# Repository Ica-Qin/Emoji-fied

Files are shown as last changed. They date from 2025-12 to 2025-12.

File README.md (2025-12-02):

# Emoji-fied: Tangible Emotion-to-Bitmap Machine System
## Advanced-Final-Project-Peiyang-Qin

*A physical installation visualising how machines simplify and categorise human emotions.*

[Thesis](PeiyangQin_Emoji-fied.pdf)

---

## ⭐ Overview

This project builds a complete real-time pipeline that transforms **facial expression → emotion label → bitmap → printed material output**.  
Using an OpenMV CAM 7 Plus, Arduino Mega 2560 Pro, three thermal printers and 4 fans, the system materialises the computational reduction of human emotion into discrete, machine-readable “signals”.

The installation visualises the hidden process of emoji-fication described in the thesis.

---

## 🎬 Demo Video

https://github.com/user-attachments/assets/3ee92d83-e0cc-42b4-839e-c0125d08e00f

---

## 🖼 Showcase Photo

showcase03

showcase01

test2
test3


---

## 🧩 System Overview

### 1. Facial Input (OpenMV CAM 7 Plus)
- Real-time face detection  
- Lightweight expression classifier trained with FER2013 + custom photos  
- Bitmap conversion and serial transmission  
- Outputs: **emotion label + confidence score + 1-bit bitmap**  

### 2. Arduino Mega 2560 Pro (Central Controller)
- Receives serial data from OpenMV  
- Routes print jobs using **three hardware serial ports**  
- Manages thermal printers and fan activation  
- Operates printers at **9600 baud** (115200 produced garbled output)  

### 3. Thermal Printers (3-way categorical output)
| Printer | Paper Colour | Emotion Categories |
|---|---|---|
| Printer 1 | Yellow | Happy, Surprise |
| Printer 2 | Blue | Sad |
| Printer 3 | Green | Fear, Angry |

### 4. Mechanical Output (Fan)
- Fan activates for **30 seconds** after each print  
- Creates drifting movement to emphasise emotion, “signals” becoming simplified or lost  

---

## 🔧 Hardware

- OpenMV CAM 7 Plus  
- Arduino Mega 2560 Pro  
- 58mm thermal printers × 3  
- LM2596 buck converter (9V → 5V)  
- Relay module (fan control)  
- 9V power supply  
- Aluminium linear shafts + 3D printed brackets  
- PVC plates + iron net for airflow shaping  

---

## 💻 Code

### 📁 [OpenMV Code](Codes/OpenMV.py)
- Face detection  
- Emotion classification  
- Bitmap generation  
- Serial output  

### 📁 [Arduino Code](Codes/Arduino)
- Receives bitmap + emotion score  
- Chooses printer port  
- Sends bitmap to printer  
- Activates fan

### Logs
[Development Logs](Development_Log.md)

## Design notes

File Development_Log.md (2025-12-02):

# Development & Iteration Log  
*Process documentation for OpenMV + Arduino system*

This document records the major iterations, problems and decisions made during the development of the installation.  
It is divided into two parts: **OpenMV iterations** and **Arduino iterations**.

---

# 1. OpenMV Iterations

## 1.1 Initial Attempt: Custom CNN Model (Failed)
- Trained a CNN using **Keras + FER2013** on PC.
- Converted the model into **TensorFlow Lite**.
- Attempted to load on OpenMV CAM 7 Plus.
- **Issues encountered:**
  - OpenMV did not have enough RAM → *MemoryError*
  - Unsupported TFLite operators → *conversion failure*
  - Inference speed too slow → *not real-time*
 
屏幕截图 2025-11-25 004311

- **Decision:** Abandon custom model and switch to OpenMV’s built-in lightweight classifier.

---

## 1.2 Switching to Built-in Expression Classifier
- Adopted OpenMV’s example model for **emotion classification**.
- Advantages:
  - Real-time inference
  - Fully compatible with OpenMV hardware
  - Small model size
- **Added training data**:
  - Supplemented with self-captured facial photos to reduce dataset bias.
  - Adjusted lighting and positioning for more stability.


---

## 1.3 Face Detection → Emotion Classification Pipeline
- Integrated Haar-like face detection with the classifier.
- Encountered a bug where:
  - Expression classification ran *even when no face was present* → random scores printed.
- **Fix:**
  - Add explicit face-detection threshold.
  - Only classify when a face is detected.

---

## 1.4 Bitmap Generation & Serial Output
- Converted ROI face images into **1-bit bitmaps**.
- Implemented byte-packet sending to Arduino.
- Challenges:
  - OpenMV’s serial port sends characters one-by-one.
  - Needed to tune frame size to avoid overflow.
- Final result:
  - Stable bitmap transmission aligned with emotion label and score.

---

# 2. Arduino Iterations

## 2.1 Early Design: Handshake Protocol (Failed)
- Initial plan: a **2-step handshake** between Arduino ↔ OpenMV.
- Process:
  - Arduino sends `"start next loop"`
  - OpenMV detects face + sends emotion
  - Arduino sends `"start img"` for bitmap
- **Problem discovered:**
  - OpenMV receives serial commands **letter-by-letter**
  - Handshake timing is constantly desynchronised
  - System frequently **froze** or missed messages

**Decision:** Remove handshake entirely → switch to one-directional control.

---

## 2.2 Final Design: One-Directional Trigger Flow
- Arduino sends a single `"S"` command to OpenMV.
- OpenMV performs:
  - Face detection  
  - Emotion classification  
  - Bitmap sending  
- Arduino routes data to the correct printer.
- This eliminated all freeze issues and allowed continuous looping.

---

## 2.3 Thermal Printer Baud Rate Debugging
- Initially used **115200 baud** for faster printing.  
- Result: printers output **garbled characters**.
- Found printer documentation stating:
  - **Supported baud rate = 9600**
- Updated code accordingly → printing became stable.

---

## 2.4 Multi-Serial Routing for 3 Printers
- Arduino Mega 2560 Pro chosen for **multiple hardware serial ports**.
- Mapping:
  - Serial1 → OpenMV
  - Serial2 → Printer 1
  - Serial3 → Printer 2
  - Serial4 → Printer 3
- Implemented routing logic based on emotion labels.

---

## 2.5 Fan Activation Logic
- Used **D9 + relay module**.
- Fan turns on for **30 seconds** after each print.
- Initial timing caused overlap when prints were frequent.
- Improved logic:
  - Reset the timer only after the previous cycle finishes.

---

# 3. Wiring and Soldering

## One Mistake
- I happened to connect rx with rx and tx with tx at first, leading to no information switches between Arduino and OpenMV.

## Wiring & Power Design



3d8b83060efac5b319d6ebcdcdfdaabd



wiring



## Frame Instalment





---

# 4. Summary of Key Insights
- Handshake-based embedded communication is unstable on OpenMV; **one-way triggers** are more reliable.
- Emotional classification errors shape the *meaning* of the work rather than being purely technical problems.
- Physical printing reveals machine logic as **material artefacts**—bitmaps, distortions, noise.
- Lightweight embedded ML always involves **reduction**, aligning with the concept of emoji-fication.

---

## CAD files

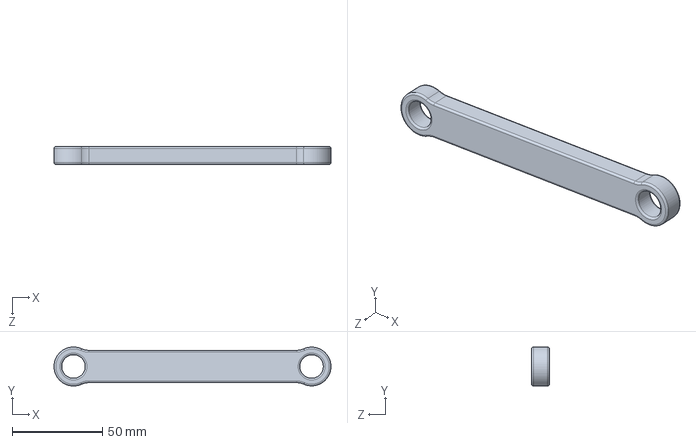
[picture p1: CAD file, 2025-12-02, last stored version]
3D Models/middle connettion.SLDPRT
153.6 x 21.6 x 10.0 mm

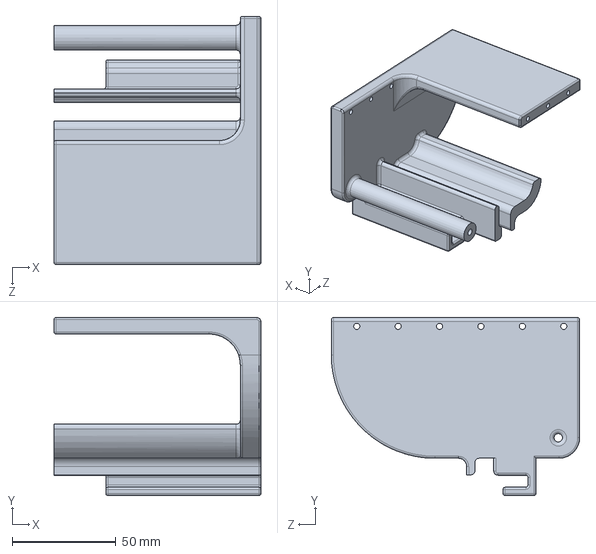
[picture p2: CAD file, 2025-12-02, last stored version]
3D Models/printer holder.SLDPRT
100.0 x 86.0 x 120.0 mm

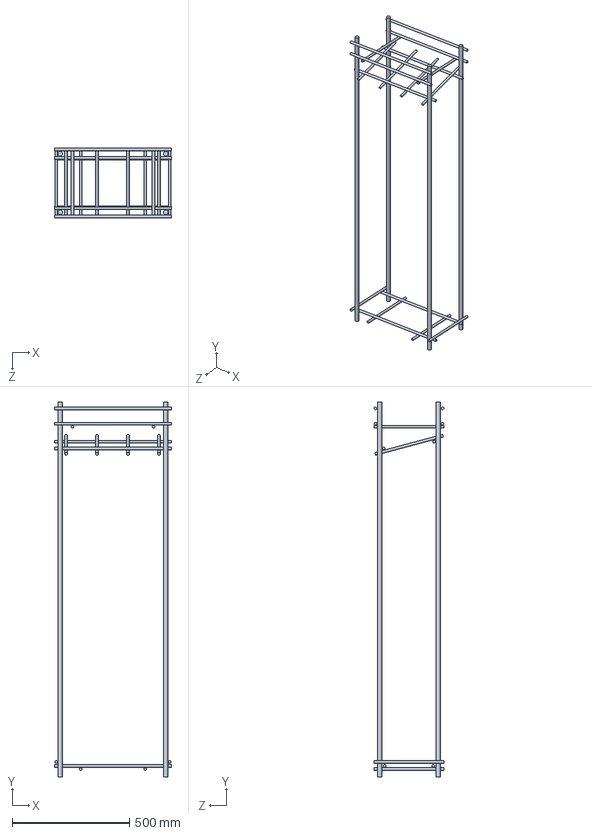
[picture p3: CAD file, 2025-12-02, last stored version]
3D Models/frame_not print.SLDPRT
500.0 x 1600.0 x 300.0 mm

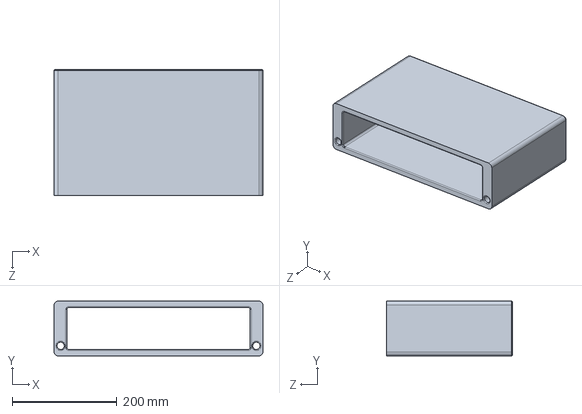
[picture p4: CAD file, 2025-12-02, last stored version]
3D Models/upper box.SLDPRT
398.8 x 104.8 x 240.0 mm

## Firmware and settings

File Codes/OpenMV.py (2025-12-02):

# ========== main.py  OpenMV：等待 'S' → 人脸 + 表情识别 → 浅色 Polaroid 风格打印 ==========

import sensor, image, time, ml
from pyb import UART, LED

# ---------- 0. LED ----------
led_red   = LED(1)
led_green = LED(2)
led_blue  = LED(3)

def blue_blink_idle(now_ms, last_blink_ms, interval_ms=5000):
    if time.ticks_diff(now_ms, last_blink_ms) >= interval_ms:
        led_blue.toggle()
        return now_ms
    return last_blink_ms

# ---------- 1. 摄像头 ----------
sensor.reset()
sensor.set_pixformat(sensor.GRAYSCALE)
sensor.set_framesize(sensor.QVGA)  # 320x240
sensor.skip_frames(time=2000)

clock = time.clock()

# ---------- 2. 人脸检测模型 ----------
face_cascade = image.HaarCascade("/rom/haarcascade_frontalface.cascade", stages=25)

# ---------- 3. 表情识别模型 ----------
model  = ml.Model("trained.tflite", load_to_fb=True)
labels = [line.rstrip("\n") for line in open("labels.txt")]

# ---------- 4. UART ----------
uart = UART(1, 9600, timeout_char=100)

# ---------- 5. 状态机 ----------
INFER_INTERVAL = 2000
active         = False
last_infer     = 0
last_blink     = time.ticks_ms()

# ---------- 发送表情 ----------
def send_expression(label, score):
    msg = "EMO,%s,%.3f\n" % (label, score)
    uart.write(msg)
    print("[OpenMV] Sent:", msg.strip())


# ========== 🌟最终版：Polaroid / 浅色风格 send_image ==========
def send_image(src_img, label, score):
    # ------- 复制原图 -------
    out = src_img.copy()

    # ------- 1. 柔化图像（降噪） -------
    out.gaussian(1)

    # ------- 2. 降对比度（偏浅） -------
    out.gamma_corr(gamma=0.80)

    # ------- 3. 提亮（让整体更白） -------
    out.midpoint(1, bias=0.55)

    # ------- 4. 素描强化（轻微锐化） -------
    try:
        out.laplacian(1, sharpen=True)
    except:
        pass

    # ------- 5. 在底部加白条 + 表情文字 -------
    bar_h = 25
    out.draw_rectangle(0, out.height()-bar_h, out.width(), bar_h,
                       color=255, fill=True)
    text = "%s (%.2f)" % (label, score)
    out.draw_string(5, out.height()-22, text, color=0)

    # ------- 6. 打印前：轻量去噪 -------
    out.mean(1)

    # ------- 7. 伪灰度阈值（关键：偏浅） -------
    TH = 60  # 150~170 更浅更白，也不会白纸

    # ------- 发送头部 -------
    w = out.width()
    h = out.height()
    uart.write("IMG,%d,%d\n" % (w, h))
    print("[OpenMV] Sent header: IMG,%d,%d" % (w, h))

    led_red.on()

    # ------- 8. 按行发送位图 -------
    for y in range(h):
        row = []
        for x in range(w):
            p = out.get_pixel(x, y)
            row.append("1" if p < TH else "0")
        uart.write("".join(row) + "\n")

    led_red.off()
    print("[OpenMV] Image sent (Polaroid浅色风).")


# ========== 主循环 ==========
print("[OpenMV] Ready. Waiting for 'S' from Arduino...")

while True:
    clock.tick()
    img = sensor.snapshot()
    now = time.ticks_ms()

    # ===== IDLE：等待 S =====
    if not active:
        last_blink = blue_blink_idle(now, last_blink)
        if uart.any():
            ch = uart.read(1)
            if ch == b'S':
                led_blue.off()
                led_green.on()
                print("[OpenMV] Got 'S' — start session")
                time.sleep_ms(150)
                led_green.off()
                active     = True
                last_infer = 0
        continue

    # ===== ACTIVE：检测阶段 =====
    faces = img.find_features(face_cascade, threshold=0.5, scale_factor=1.5)
    if not faces:
        continue

    # 最大面积人脸
    x, y, w, h = max(faces, key=lambda f: f[2] * f[3])
    img.draw_rectangle(x, y, w, h, color=255)

    # 表情推理节流
    now = time.ticks_ms()
    if time.ticks_diff(now, last_infer) < INFER_INTERVAL:
        continue
    last_infer = now

    # 裁剪为 48x48（你的模型必须这样处理）
    face_img = img.copy()
    s = min(48.0/w, 48.0/h)
    face_img.crop(x_scale=s, y_scale=s, roi=(x, y, w, h))

    scores = model.predict([face_img])[0].flatten().tolist()
    idx    = scores.index(max(scores))
    label  = labels[idx]
    score  = scores[idx]

    print("Expression:", label, "Score:", score)

    # ===== 发送表情 + Polaroid风整图 =====
    send_expression(label, score)
    send_image(img, label, score)

    # 回到空闲
    active      = False
    last_blink  = time.ticks_ms()
    led_blue.off()
    led_green.off()
    led_red.off()
    print("[OpenMV] Session done.\n")
